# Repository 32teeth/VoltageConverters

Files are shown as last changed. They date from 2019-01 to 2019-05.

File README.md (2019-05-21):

# A Collection of Voltage Converters
> See List Below

Herein are a collection of Voltage / Boost Converters built for different projects using different ICs
Best thing to do is read the whitepapers if you decide to make your own

| Name | Gerber | Production |
| --- | --- | --- |
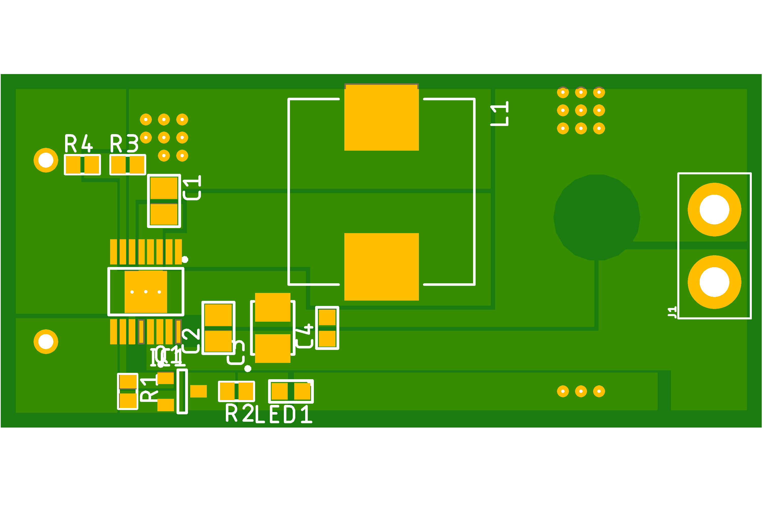
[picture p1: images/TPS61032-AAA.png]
TPS61032-AAA
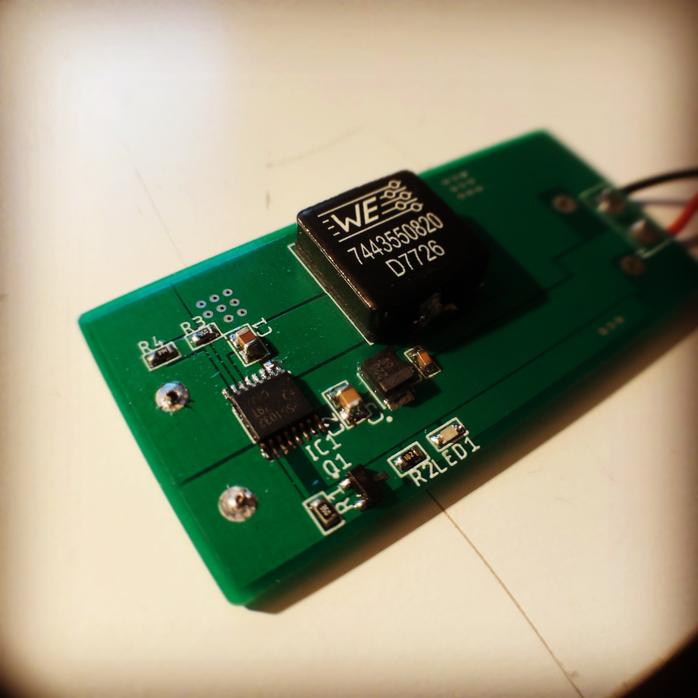
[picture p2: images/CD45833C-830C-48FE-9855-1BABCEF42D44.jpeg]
TPS61032-AAA Production
| TPS61032-AAA |  |  |
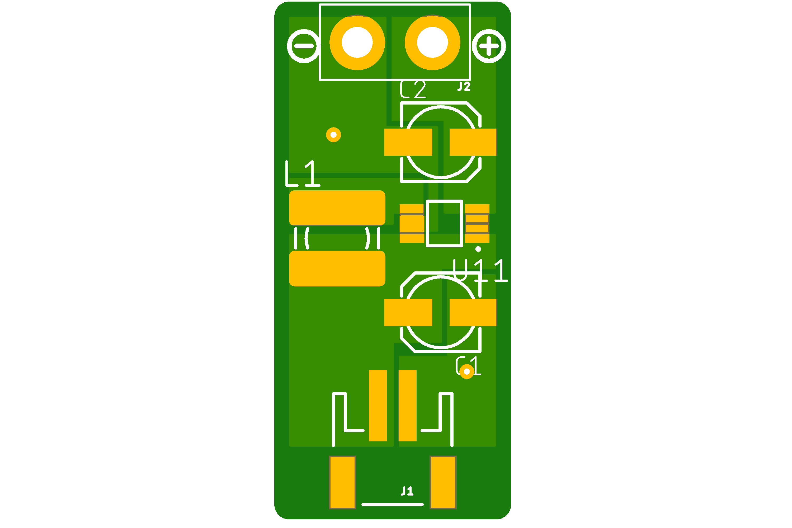
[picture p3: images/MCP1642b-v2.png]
MCP1642b
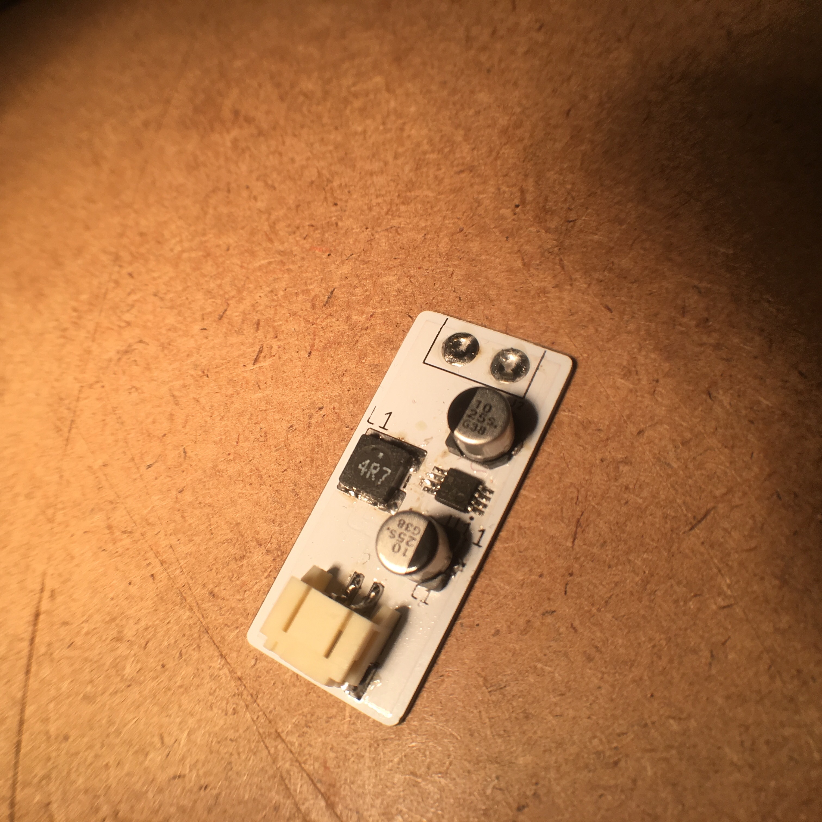
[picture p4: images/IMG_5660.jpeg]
MCP1642b Production
| MCP1642b |  |  |
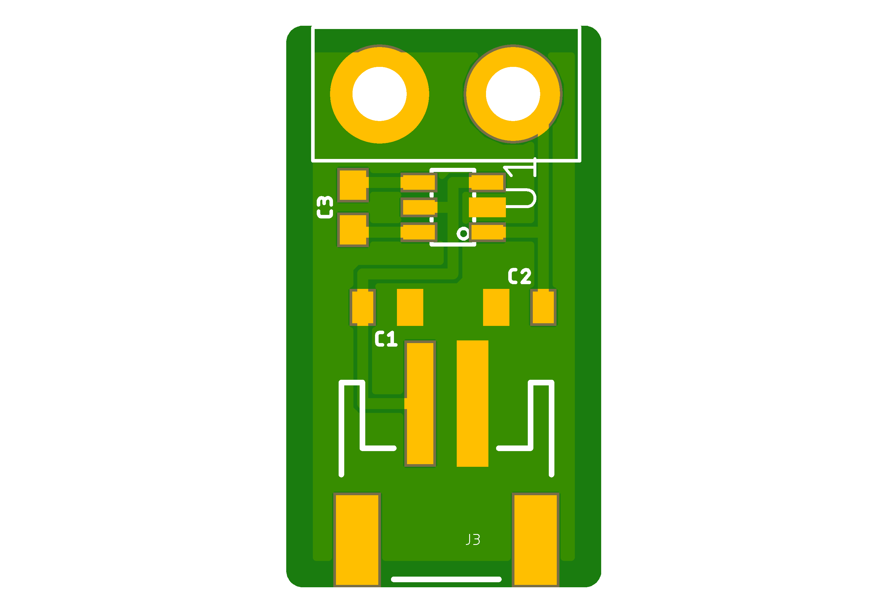
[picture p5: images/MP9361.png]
MP9361
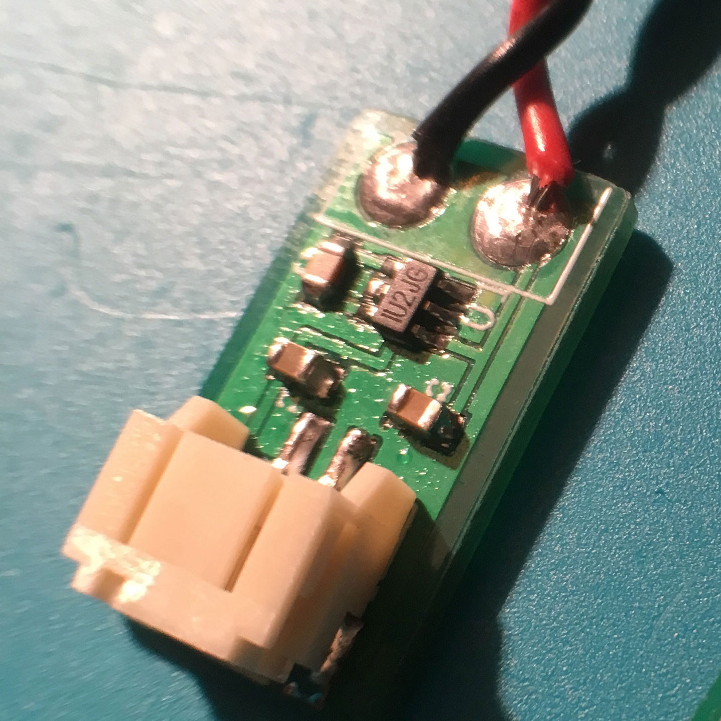
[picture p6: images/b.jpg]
MP9361 Production
| MP9361 |  |  |
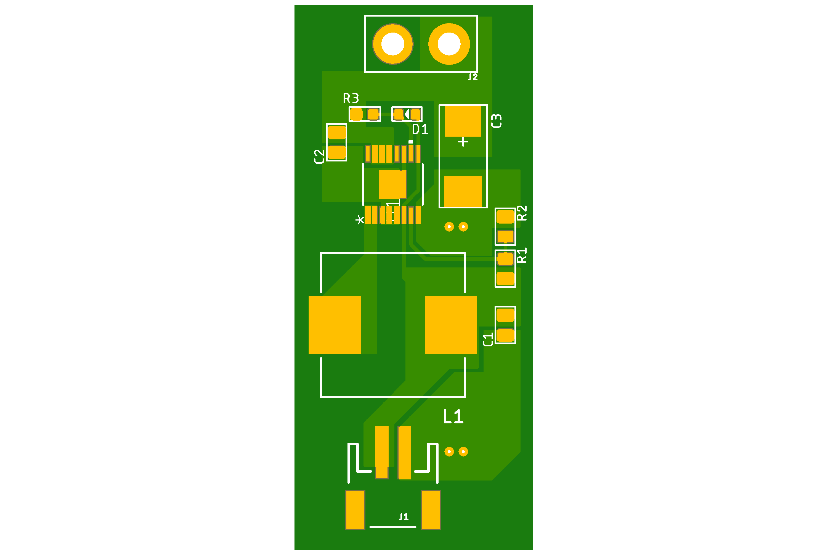
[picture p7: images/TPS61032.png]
TPS61032
| TPS61032 |  |  |
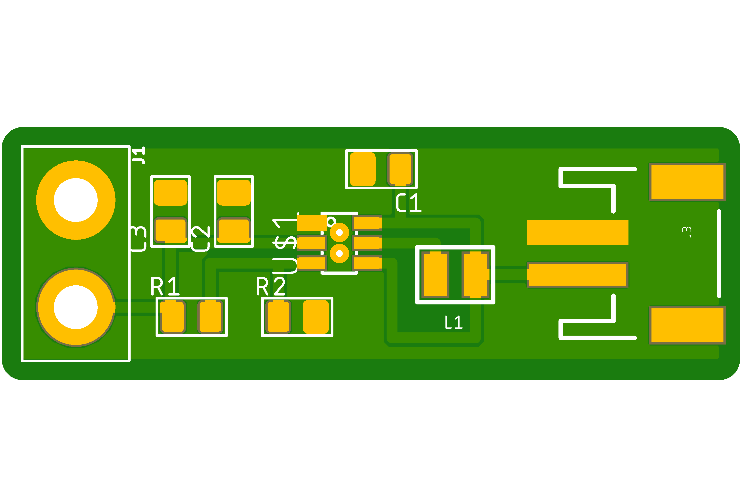
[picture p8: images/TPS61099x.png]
TPS61099x
| TPS61099x |  |  |
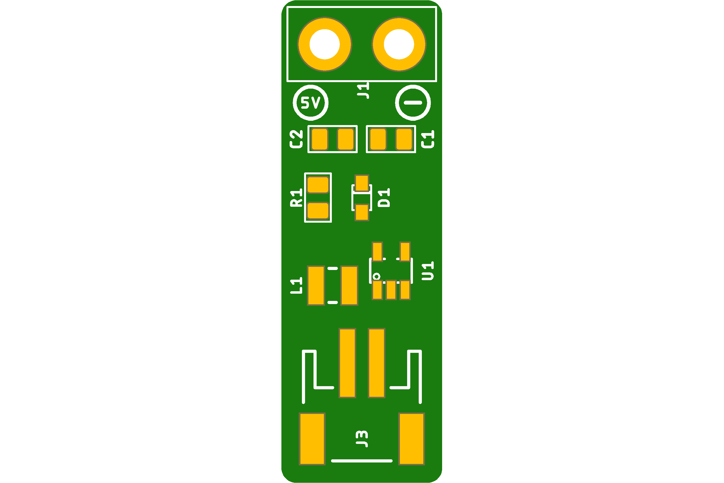
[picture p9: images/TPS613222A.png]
TPS613222A
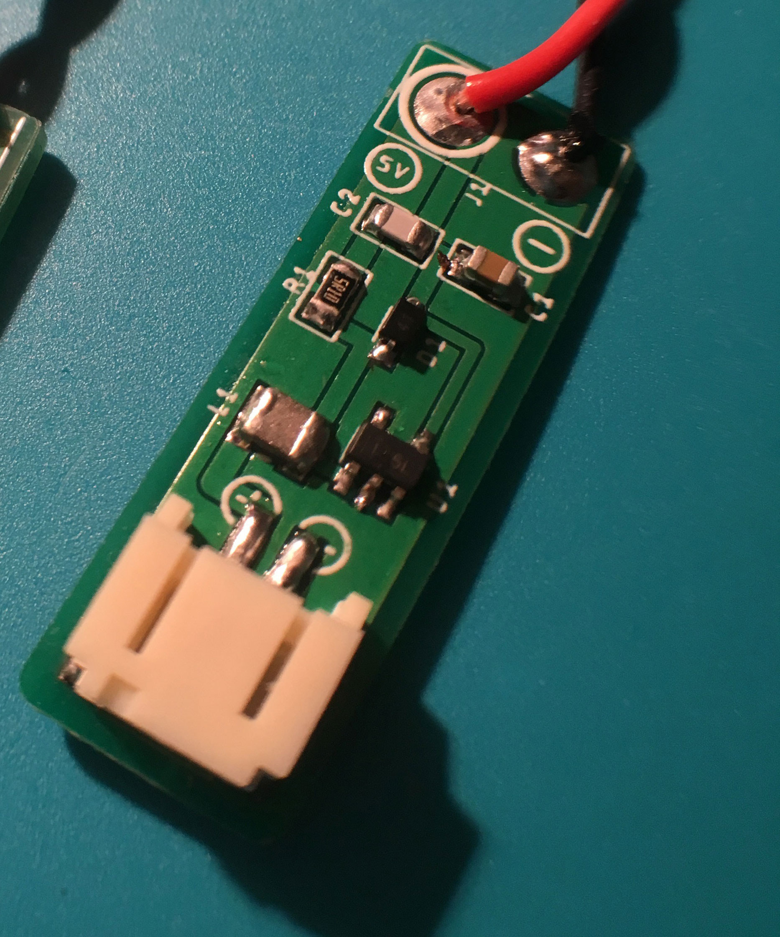
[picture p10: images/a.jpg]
TPS613222A Production
| TPS613222A |  |  |

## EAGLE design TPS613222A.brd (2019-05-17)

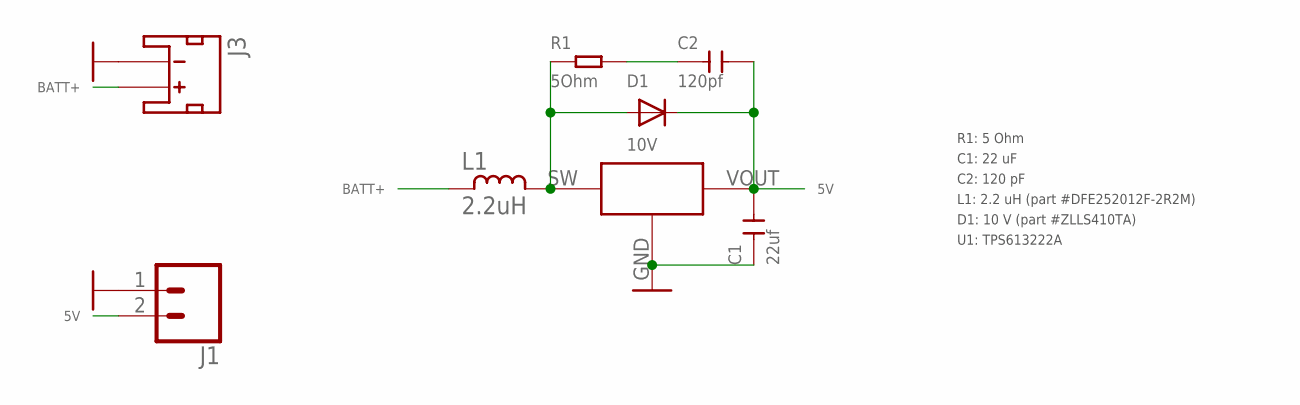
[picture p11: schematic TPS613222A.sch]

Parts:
C1: 22uf; C0805
C2: 120pf; C0805
D1: 10V; SOD-323F
J1: CONN_02PTH4; 1X02_XTRA_BIG
J3: Batt Conn; JST-2-SMD
L1: 2.2uH; L1008CS
R1: 5Ohm; R0805
U1: TPS613222A

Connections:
5V: C1.2, C2.2, D1.C, J1.2, U1.VOUT
BATT+: J3.2 (+), L1.1
GND: C1.1, J1.1, J3.1 (-), U1.GND
unnamed: D1.A, L1.2, R1.1, U1.SW
unnamed: C2.1, R1.2

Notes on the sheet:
R1: 5 Ohm C1: 22 uF C2: 120 pF L1: 2.2 uH (part #DFE252012F-2R2M) D1: 10 V (part #ZLLS410TA) U1: TPS613222A

Board: 2 copper layers, 8 parts (0 on the bottom side), 5 nets, no tracks yet.

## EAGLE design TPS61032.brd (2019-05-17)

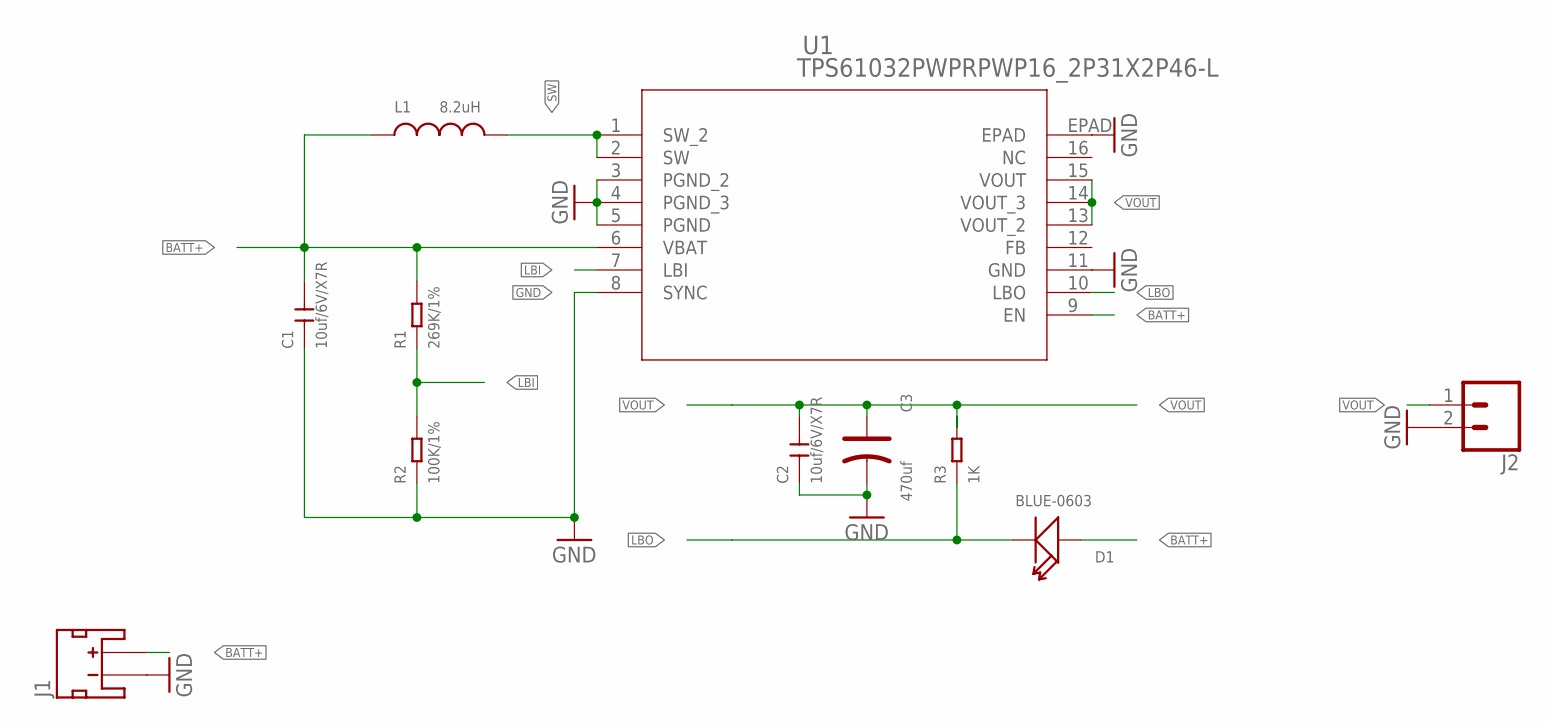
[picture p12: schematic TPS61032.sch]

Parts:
C1, C2: 10uf/6V/X7R; C0805
C3: 470uf; AVX-D
D1: BLUE-0603; LED-0603
J1: JST_2MM_MALE; JST-2-SMD
J2: CONN_02PTH4; 1X02_XTRA_BIG
L1: 8.2uH; 7443550820
R1: 269K/1%; R0805
R2: 100K/1%; R0805
R3: 1K; R0603
U1: TPS61032PWPRPWP16_2P31X2P46-L; PWP16_2P31X2P46-L

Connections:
BATT+: C1.2, D1.+, J1.2 (+), L1.1, R1.2, U1.6 (VBAT), U1.9 (EN)
GND: C1.1, C2.1, C3.-, J1.1 (-), J2.2, R2.1, U1.3 (PGND_2), U1.4 (PGND_3), U1.5 (PGND), U1.8 (SYNC), U1.11 (GND), U1.EPAD
LBI: R1.1, R2.2, U1.7 (LBI)
LBO: D1.-, R3.1, U1.10 (LBO)
SW: L1.2, U1.1 (SW_2), U1.2 (SW)
VOUT: C2.2, C3.+, J2.1, R3.2, U1.13 (VOUT_2), U1.14 (VOUT_3), U1.15 (VOUT)

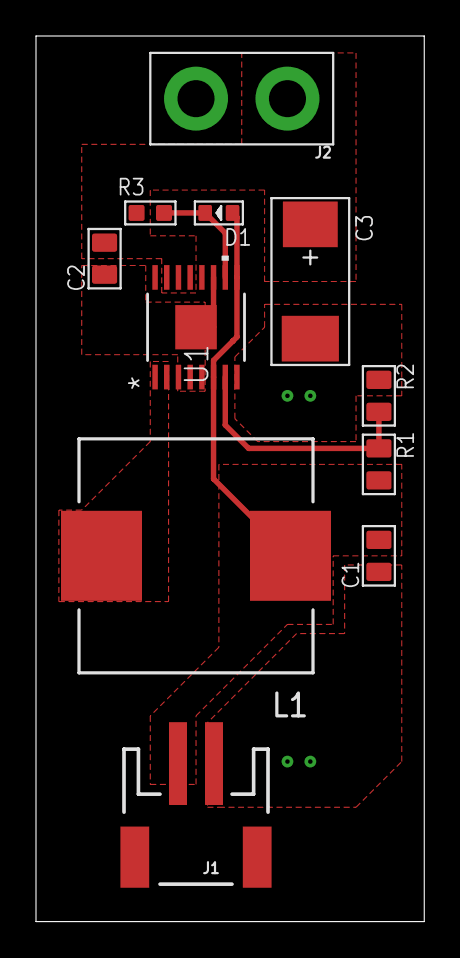
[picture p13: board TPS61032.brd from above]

Board: 2 copper layers, 21.6 x 49.2 mm, 11 parts (0 on the bottom side), 6 nets.

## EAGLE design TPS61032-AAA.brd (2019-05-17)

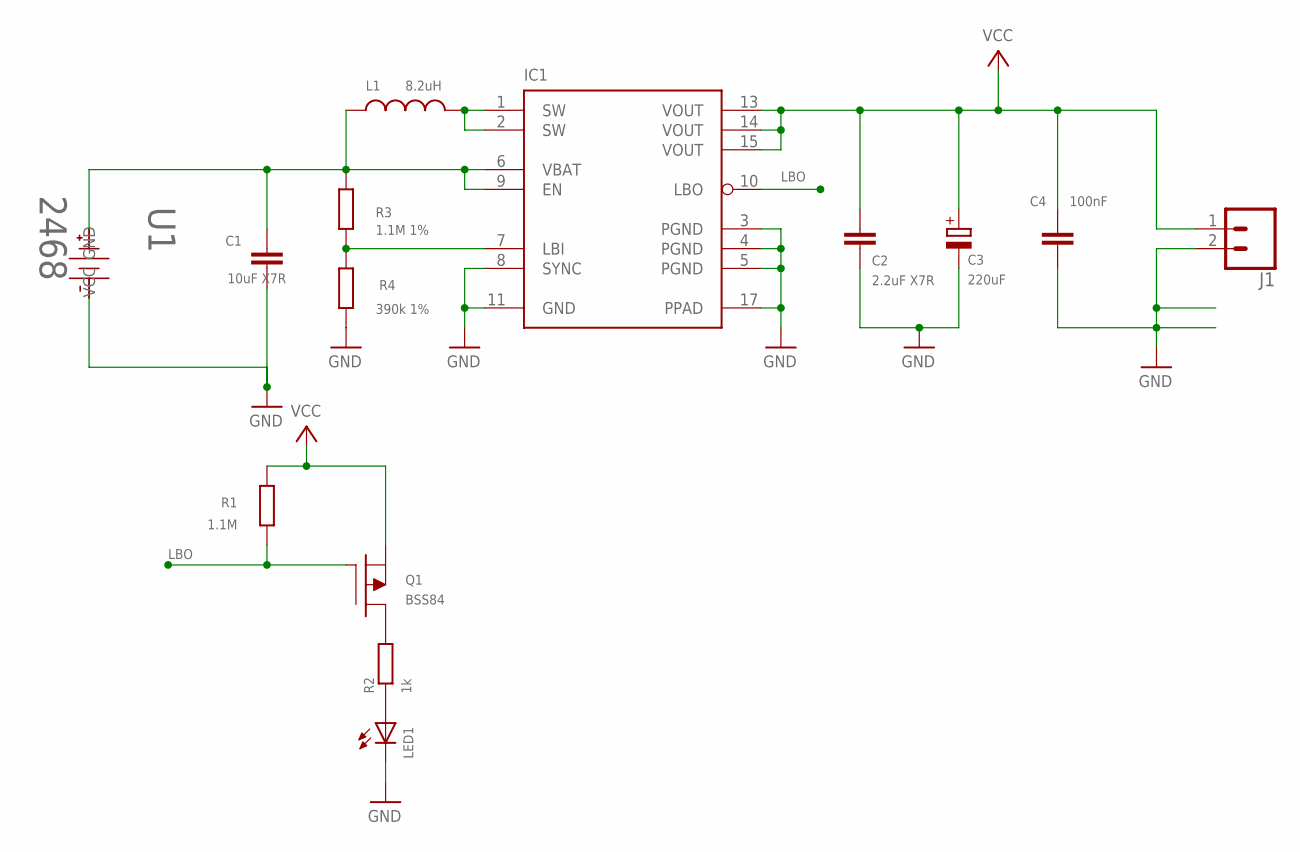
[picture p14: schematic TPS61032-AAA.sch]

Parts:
C1: 10uF X7R; CAPC2012X130N
C2: 2.2uF X7R; CAPC2012X130N
C3: 220uF; CAPMP3528X210N
C4: 100nF; CAPC1608X55N
IC1: TPS61032; MO-153+PAD
J1: CONN_02PTH4; 1X02_XTRA_BIG
L1: 8.2uH; 7443550820
LED1: LED0603; LEDC1608X60N
Q1: BSS84; SOT95P240X110-3N
R1: 1.1M; RESC1508X63N
R2: 1k; RESC1508X63N
R3: 1.1M 1%; RESC1508X63N
R4: 390k 1%; RESC1508X63N
U1: 2468; BAT_HLDR_2468

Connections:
GND: C1.2, C2.2, C3.2 (-), C4.2, IC1.3 (PGND), IC1.4 (PGND), IC1.5 (PGND), IC1.8 (SYNC), IC1.11 (GND), IC1.17 (PPAD), J1.2, LED1.1 (C), R4.1, U1.GND
LBI: IC1.7 (LBI), R3.1, R4.2
LBO: IC1.10 (LBO), Q1.1 (GATE), R1.1
LED: LED1.2 (A), R2.1
LOW: Q1.3 (DRAIN), R2.2
SW: IC1.1 (SW), IC1.2 (SW), L1.2
VBAT: C1.1, IC1.6 (VBAT), IC1.9 (EN), L1.1, R3.2, U1.VCC
VCC: C2.1, C3.1 (+), C4.1, IC1.13 (VOUT), IC1.14 (VOUT), IC1.15 (VOUT), J1.1, Q1.2 (SOURCE), R1.2

Board: 2 copper layers, 14 parts (1 on the bottom side), 8 nets, no tracks yet.

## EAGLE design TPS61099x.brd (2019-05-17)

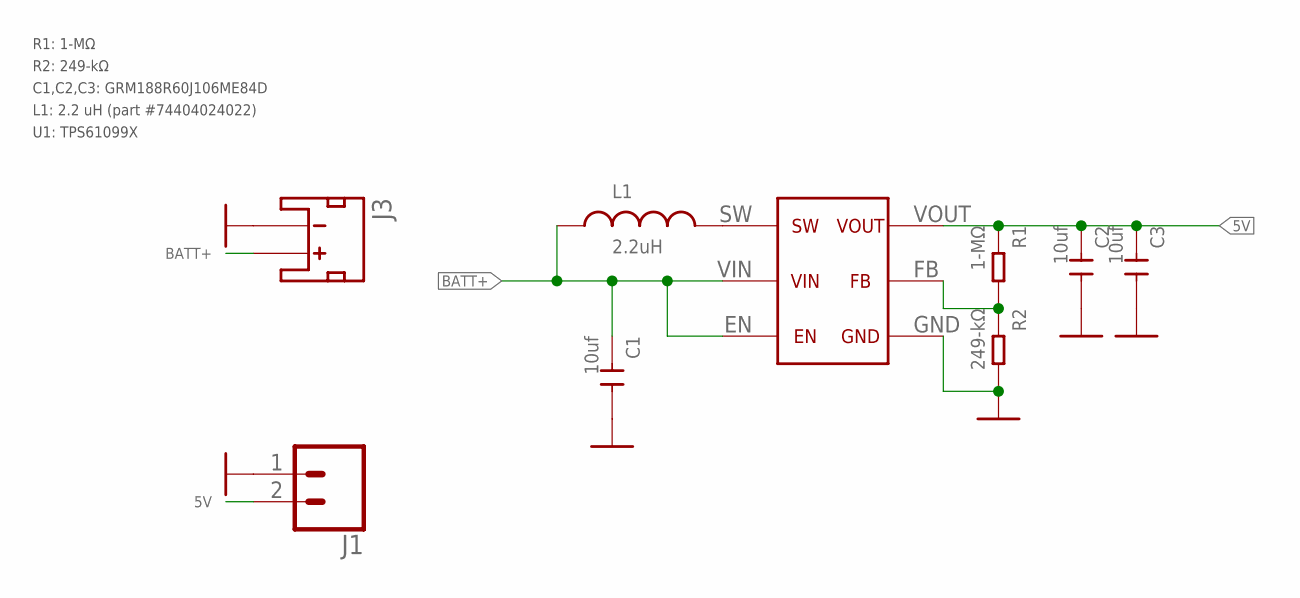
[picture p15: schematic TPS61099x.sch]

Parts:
C1, C2, C3: 10uf; C0805
J1: CONN_02PTH4; 1X02_XTRA_BIG
J3: Batt Conn; JST-2-SMD
L1: 2.2uH; WE-LQS_2512
R1: 1-MΩ; R0805
R2: 249-kΩ; R0805
U$1: TPS61099X

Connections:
5V: C2.1, C3.1, J1.2, R1.1, U$1.VOUT
BATT+: C1.1, J3.2 (+), L1.1, U$1.EN, U$1.VIN
GND: C1.2, C2.2, C3.2, J1.1, J3.1 (-), R2.2, U$1.GND
unnamed: L1.2, U$1.SW
unnamed: R1.2, R2.1, U$1.FB

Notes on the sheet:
R1: 1-MΩ R2: 249-kΩ C1,C2,C3: GRM188R60J106ME84D L1: 2.2 uH (part #74404024022) U1: TPS61099X

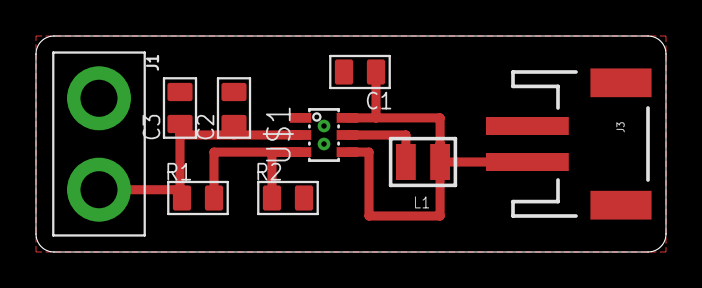
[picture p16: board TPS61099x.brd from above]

Board: 2 copper layers, 35.0 x 12.0 mm, 9 parts (0 on the bottom side), 5 nets.

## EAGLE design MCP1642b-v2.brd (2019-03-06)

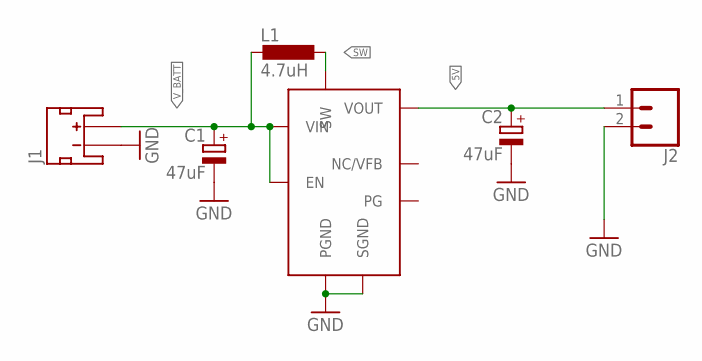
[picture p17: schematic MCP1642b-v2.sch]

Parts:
C1, C2: 47uF; 153CLV-0505
J1: JST_2MM_MALE; JST-2-SMD
J2: CONN_02PTH4; 1X02_XTRA_BIG
L1: 4.7uH; POWER-CHOKE_WE-TPC
U11: MCP1642B

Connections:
5V: C2.+, J2.1, U11.VOUT
GND: C1.-, C2.-, J1.1 (-), J2.2, U11.PGND, U11.SGND
SW: L1.1, U11.SW
V_BATT: C1.+, J1.2 (+), L1.2, U11.EN, U11.VIN

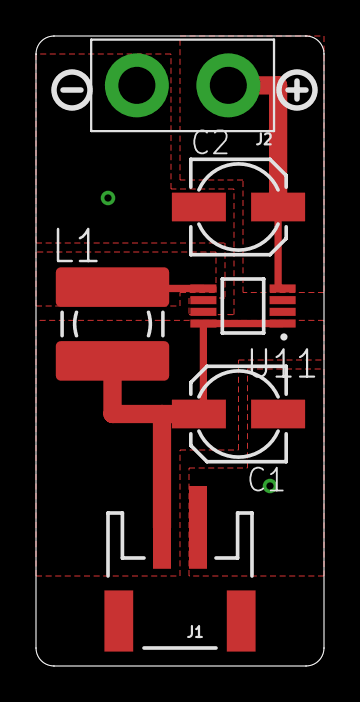
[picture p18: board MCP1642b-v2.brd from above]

Board: 2 copper layers, 16.0 x 35.0 mm, 6 parts (0 on the bottom side), 4 nets.

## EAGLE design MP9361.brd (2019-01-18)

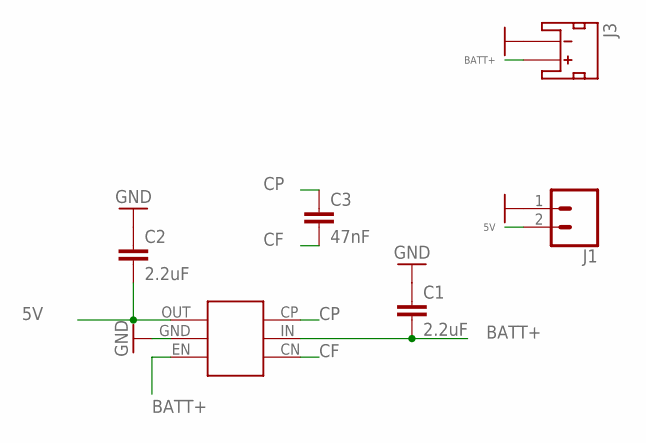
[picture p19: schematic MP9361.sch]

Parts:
C1, C2: 2.2uF; 0805
C3: 47nF; 0603
J1: CONN_02PTH4; 1X02_XTRA_BIG
J3: Batt Conn; JST-2-SMD
U1: MP9361

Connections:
5V: C2.2, J1.2, U1.OUT
BATT+: C1.2, J3.2 (+), U1.EN, U1.IN
CF: C3.2, U1.CN
CP: C3.1, U1.CP
GND: C1.1, C2.1, J1.1, J3.1 (-), U1.GND

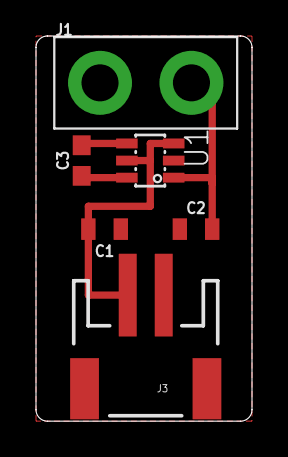
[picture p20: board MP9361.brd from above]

Board: 2 copper layers, 12.0 x 21.4 mm, 6 parts (0 on the bottom side), 5 nets.

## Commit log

2019-01-18 Fri 18 Jan 2019 11:23:44 EST - initial commit from forked private repo
    [MP9361.brd, MP9361.sch, TPS61032.brd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]
2019-01-29 Mon 28 Jan 2019 22:16:21 EST - updated MCP1642 device with planes
    [mcp1642b.brd, mcp1642b.sch]
2019-01-29 Mon 28 Jan 2019 22:17:14 EST - updated MCP1642 device with planes
    [mcp1642b.brd]
2019-03-06 Wed 6 Mar 2019 10:52:50 EST - added AAA alkaline version of TPS61032
    [TPS61032-AAA.brd, TPS61032-AAA.sch, mcp1642b.brd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]
2019-03-06 Wed 6 Mar 2019 10:53:50 EST - name change
    [MCP1642b-v2.brd, MCP1642b-v2.sch]
2019-05-17 Fri 17 May 2019 16:01:28 EDT - added README.md
    [TPS61032-AAA.brd, TPS61032-AAA.sch, TPS61032.brd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]
2019-05-18 Fri 17 May 2019 23:10:17 EDT - added README.md
    [TPS613222A.brd]

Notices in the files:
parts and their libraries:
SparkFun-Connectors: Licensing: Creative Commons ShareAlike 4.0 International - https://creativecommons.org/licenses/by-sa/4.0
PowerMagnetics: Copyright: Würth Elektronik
